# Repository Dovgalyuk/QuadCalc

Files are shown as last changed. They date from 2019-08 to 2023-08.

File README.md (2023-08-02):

# QuadCalc
Arduino-based calculator displaying bin/oct/dec/hex versions of argument and result simultaneously

Schematic: https://github.com/Dovgalyuk/QuadCalc/blob/master/pcb-avr/pcb.pdf

## Flashing

Read low fuse bits into file low:

    sudo avrdude -p m2560 -c usbtiny -U lfuse:r:low:r

Write low fuse bits from file low. It should contain single FF byte:

    sudo avrdude -p m2560 -c usbtiny -U lfuse:w:low:r

Write high fuse bits from file high. It should contain single D8 byte:

    sudo avrdude -p m2560 -c usbtiny -U hfuse:w:high:r

Write the firmware image:

    sudo avrdude -p m2560 -c usbtiny -U flash:w:calc.ino.hex:i

# Links

* MK61 hardware emulator: https://gitlab.com/vitasam/mk61s
* E-ink Pi: https://github.com/a8ksh4/paper-pi-handheld
* Handheld Linux Terminal: https://hackaday.io/project/192152-handheld-linux-terminal
* The Forth Deck: http://mynor.org/my4th

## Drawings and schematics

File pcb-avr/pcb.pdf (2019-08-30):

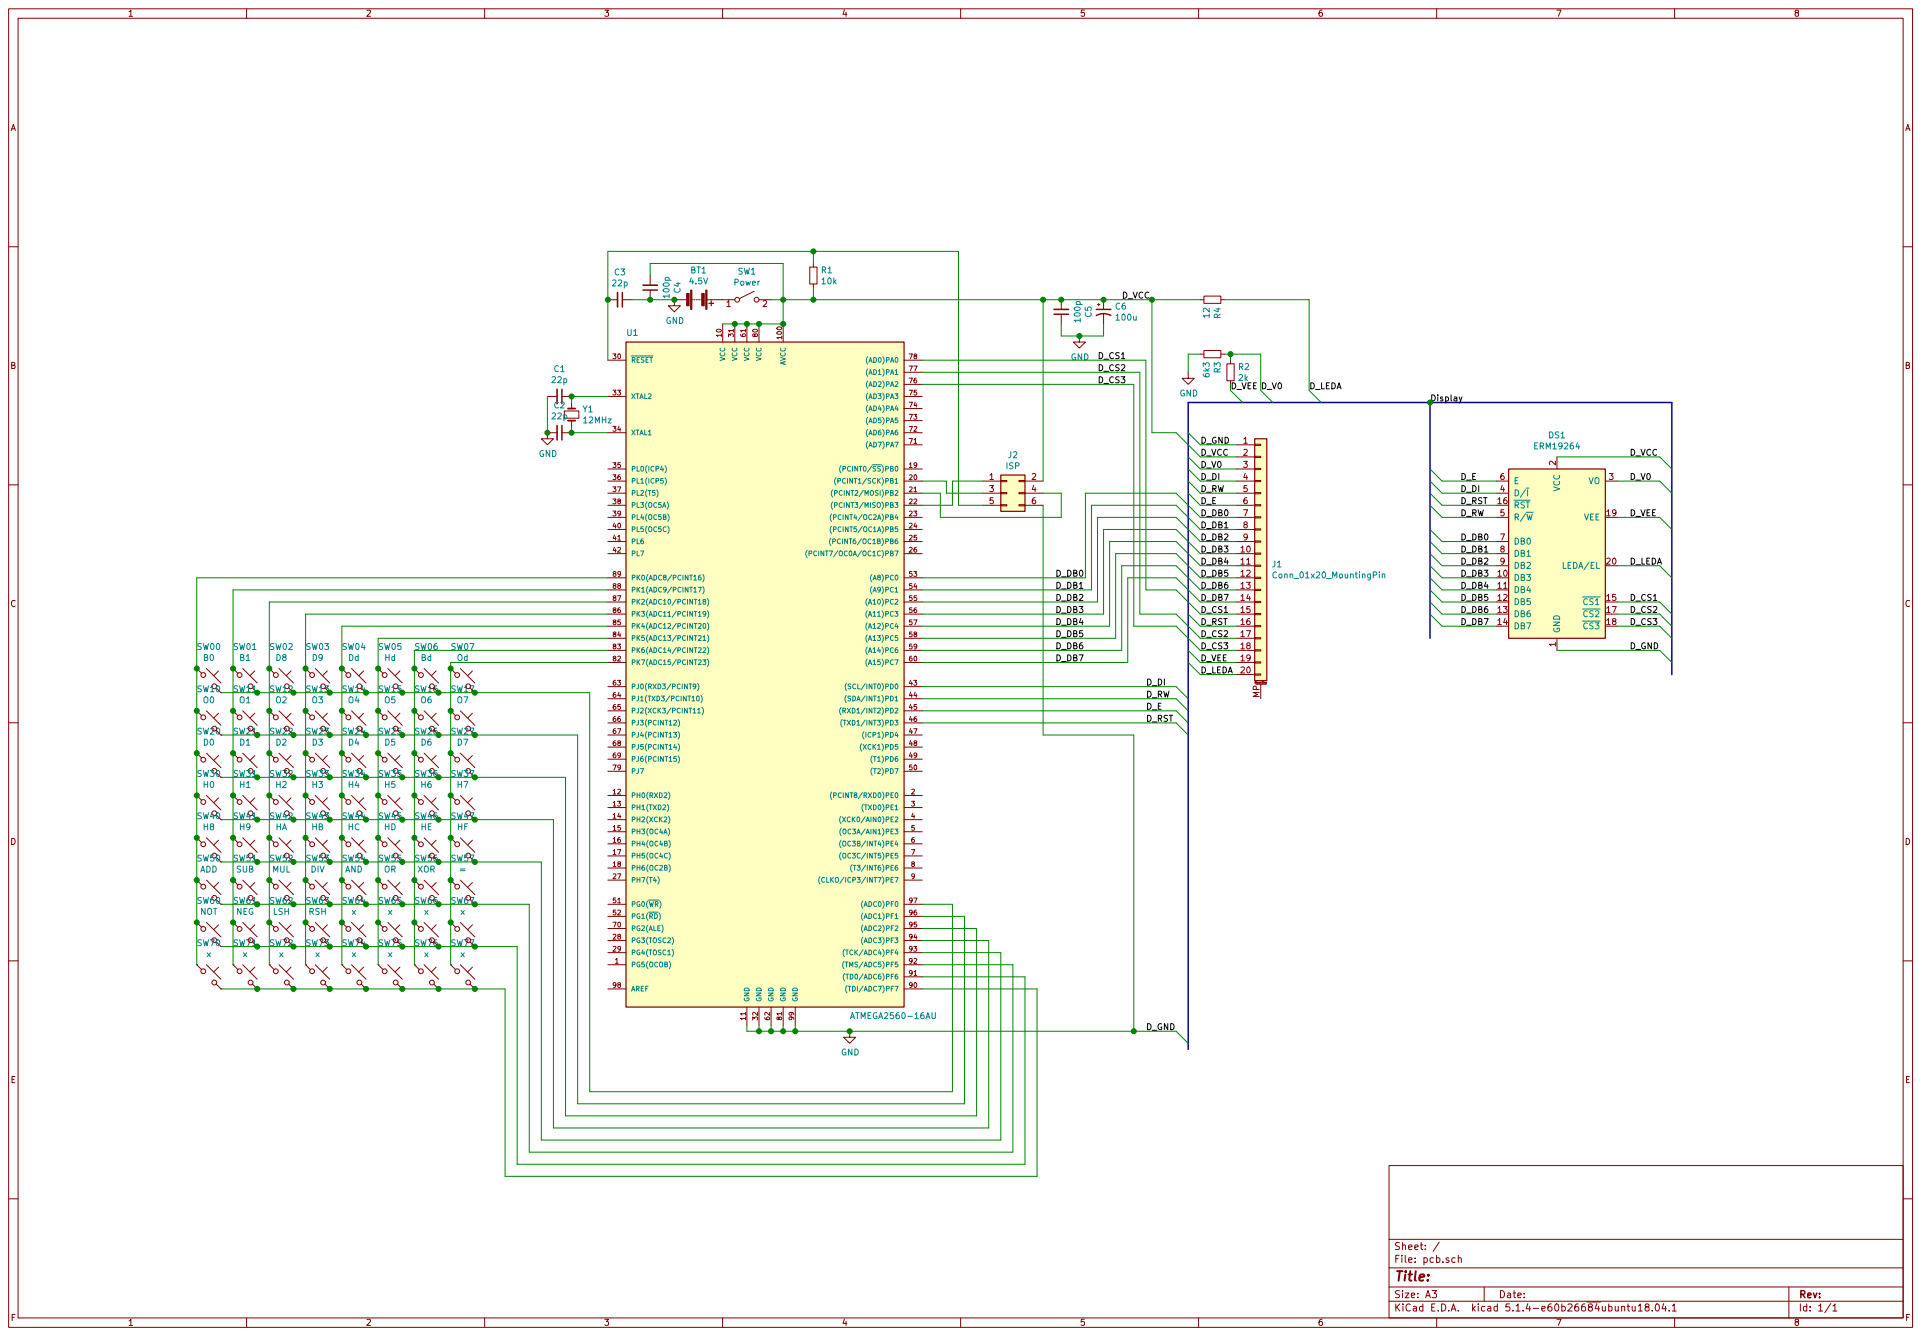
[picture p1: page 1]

File: pcb.sch Sheet: /

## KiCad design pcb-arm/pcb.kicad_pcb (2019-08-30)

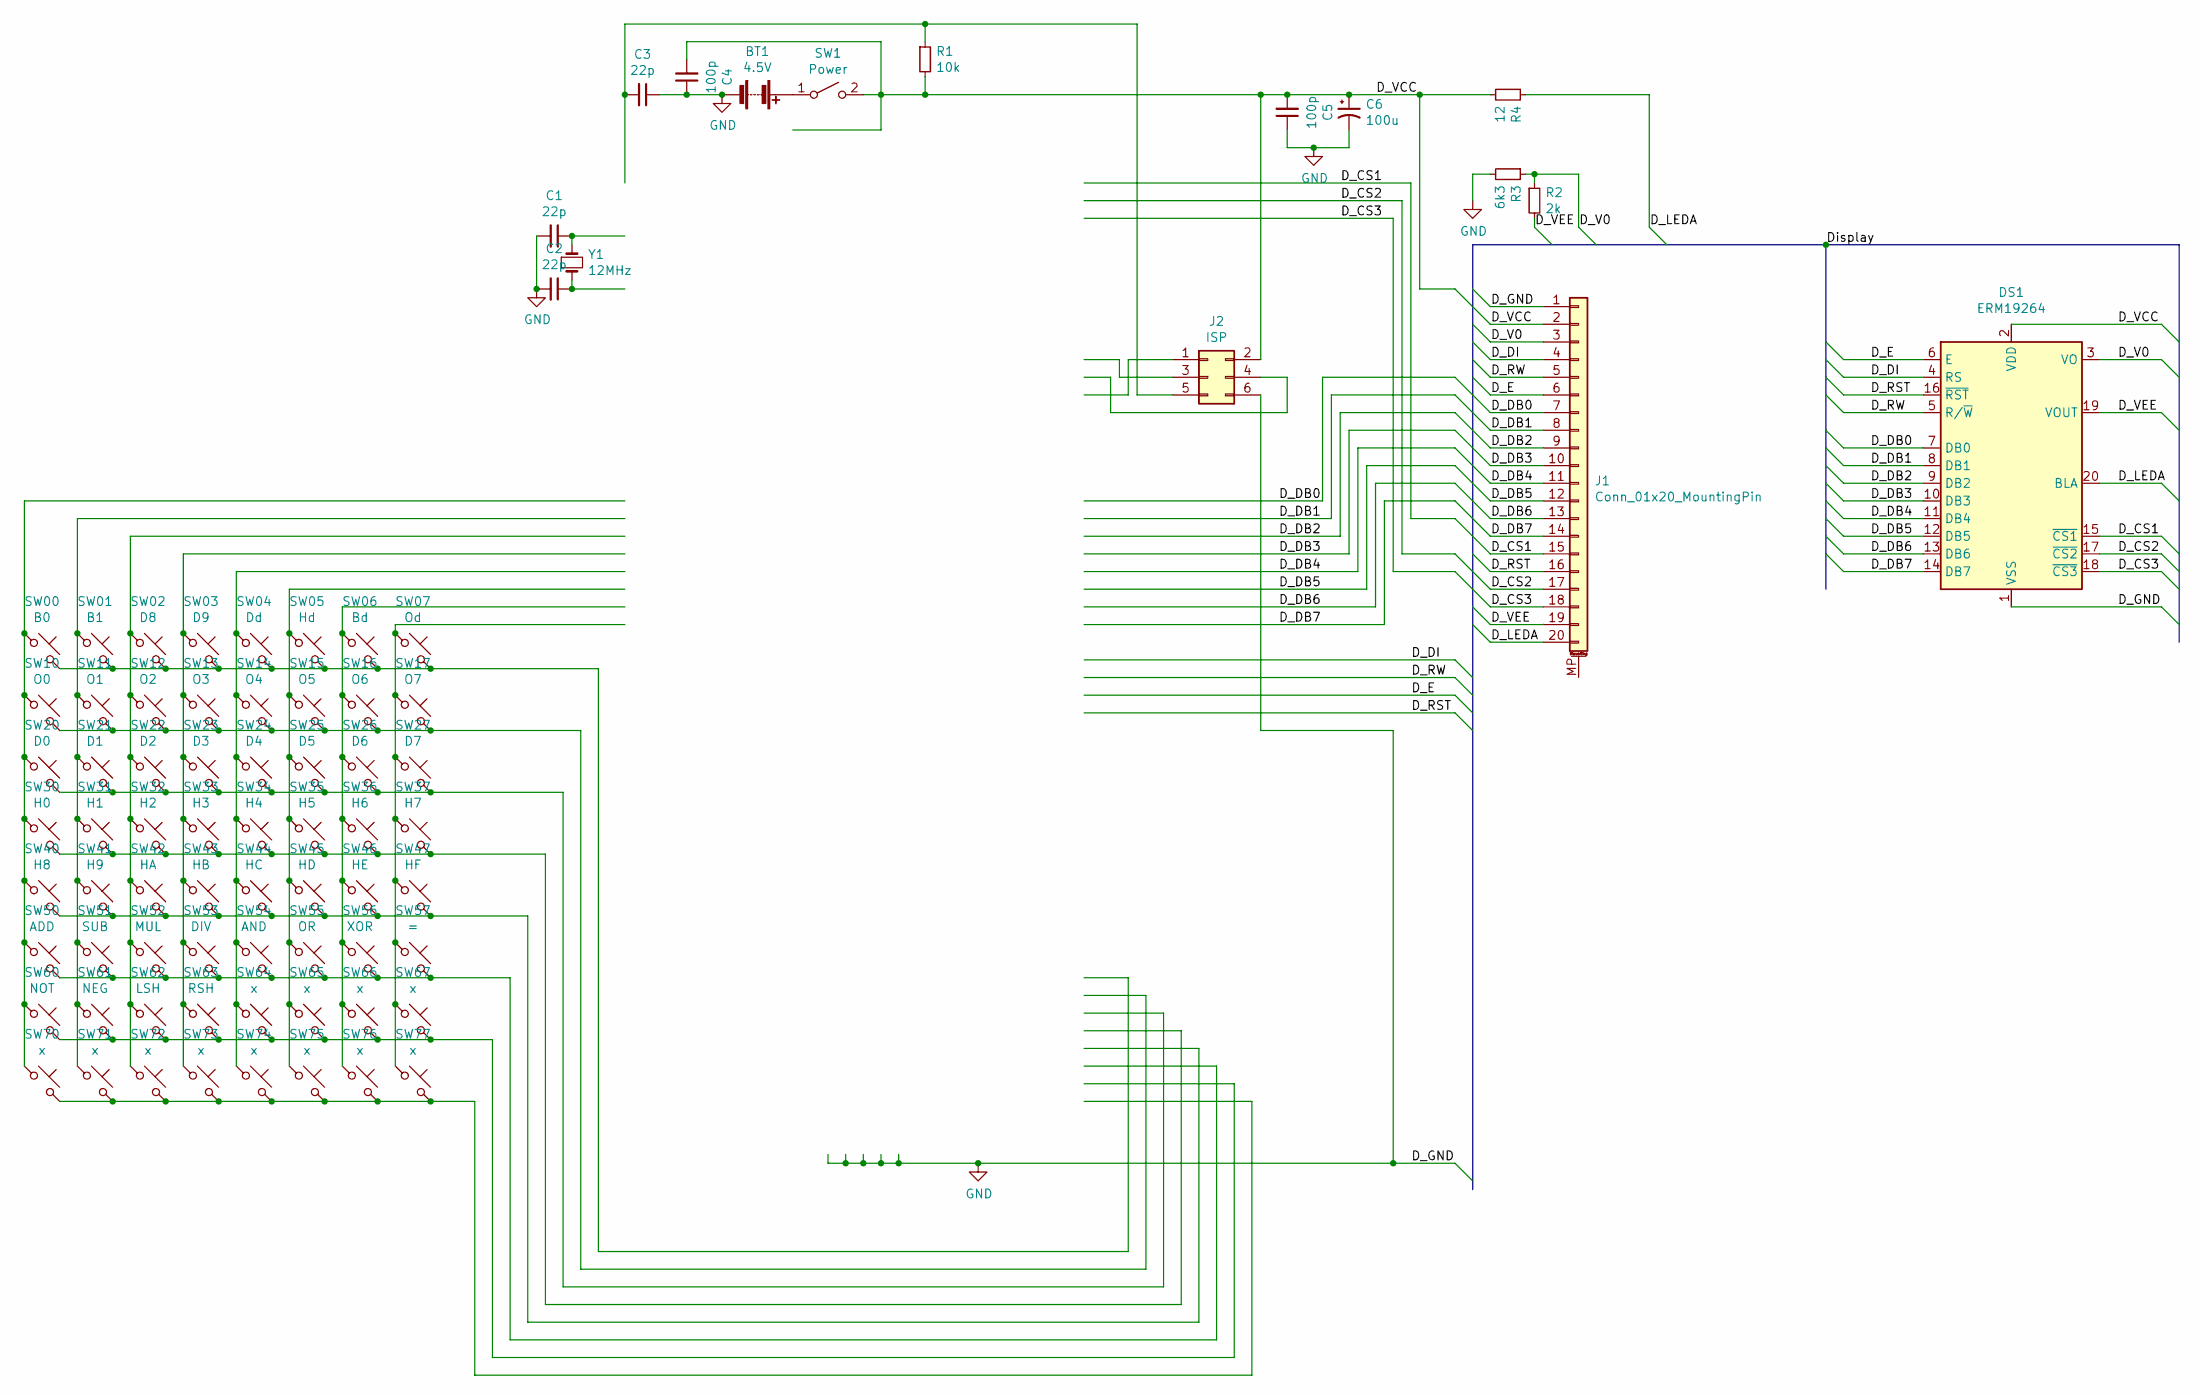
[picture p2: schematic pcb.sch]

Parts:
BT1: 4.5V; BatteryHolder_Keystone_2479_3xAAA
C1, C2, C3: 22p; C_0603_1608Metric
C4, C5: 100p; C_0603_1608Metric
C6: 100u; CP_EIA-7343-15_Kemet-W
DS1: ERM19264
J1: Conn_01x20_MountingPin; PinSocket_1x20_P2.54mm_Vertical
J2: ISP; IDC-Header_2x03_P2.54mm_Vertical
R1: 10k; R_0603_1608Metric
R2: 2k; R_0603_1608Metric
R3: 6k3; R_0603_1608Metric
R4: 12; R_0603_1608Metric
SW00: B0; SW_SPST_PTS645
SW01: B1; SW_SPST_PTS645
SW1: Power; SW_CuK_JS202011CQN_DPDT_Straight
SW02: D8; SW_SPST_PTS645
SW03: D9; SW_SPST_PTS645
SW04: Dd; SW_SPST_PTS645
SW05: Hd; SW_SPST_PTS645
SW06: Bd; SW_SPST_PTS645
SW07: Od; SW_SPST_PTS645
SW10: O0; SW_SPST_PTS645
SW11: O1; SW_SPST_PTS645
SW12: O2; SW_SPST_PTS645
SW13: O3; SW_SPST_PTS645
SW14: O4; SW_SPST_PTS645
SW15: O5; SW_SPST_PTS645
SW16: O6; SW_SPST_PTS645
SW17: O7; SW_SPST_PTS645
SW20: D0; SW_SPST_PTS645
SW21: D1; SW_SPST_PTS645
SW22: D2; SW_SPST_PTS645
SW23: D3; SW_SPST_PTS645
SW24: D4; SW_SPST_PTS645
SW25: D5; SW_SPST_PTS645
SW26: D6; SW_SPST_PTS645
SW27: D7; SW_SPST_PTS645
SW30: H0; SW_SPST_PTS645
SW31: H1; SW_SPST_PTS645
SW32: H2; SW_SPST_PTS645
SW33: H3; SW_SPST_PTS645
SW34: H4; SW_SPST_PTS645
SW35: H5; SW_SPST_PTS645
SW36: H6; SW_SPST_PTS645
SW37: H7; SW_SPST_PTS645
SW40: H8; SW_SPST_PTS645
SW41: H9; SW_SPST_PTS645
SW42: HA; SW_SPST_PTS645
SW43: HB; SW_SPST_PTS645
SW44: HC; SW_SPST_PTS645
SW45: HD; SW_SPST_PTS645
SW46: HE; SW_SPST_PTS645
SW47: HF; SW_SPST_PTS645
SW50: ADD; SW_SPST_PTS645
SW51: SUB; SW_SPST_PTS645
SW52: MUL; SW_SPST_PTS645
SW53: DIV; SW_SPST_PTS645
SW54: AND; SW_SPST_PTS645
SW55: OR; SW_SPST_PTS645
SW56: XOR; SW_SPST_PTS645
SW57: =; SW_SPST_PTS645
SW60: NOT; SW_SPST_PTS645
SW61: NEG; SW_SPST_PTS645
SW62: LSH; SW_SPST_PTS645
SW63: RSH; SW_SPST_PTS645
SW64, SW65, SW66, SW67, SW70, SW71, SW72, SW73, SW74, SW75, SW76, SW77: x; SW_SPST_PTS645
Y1: 12MHz; Crystal_SMD_SeikoEpson_MC405-2Pin_9.6x4.1mm_HandSoldering

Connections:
/D_CS1: DS1.15 (~CS1~), J1.15; also elsewhere on the board
/D_CS2: DS1.17 (~CS2~), J1.17; also elsewhere on the board
/D_CS3: DS1.18 (~CS3~), J1.18; also elsewhere on the board
/D_DB0: DS1.7 (DB0), J1.7; also elsewhere on the board
/D_DB1: DS1.8 (DB1), J1.8; also elsewhere on the board
/D_DB2: DS1.9 (DB2), J1.9; also elsewhere on the board
/D_DB3: DS1.10 (DB3), J1.10; also elsewhere on the board
/D_DB4: DS1.11 (DB4), J1.11; also elsewhere on the board
/D_DB5: DS1.12 (DB5), J1.12; also elsewhere on the board
/D_DB6: DS1.13 (DB6), J1.13; also elsewhere on the board
/D_DB7: DS1.14 (DB7), J1.14; also elsewhere on the board
/D_DI: DS1.4 (RS), J1.4; also elsewhere on the board
/D_E: DS1.6 (E), J1.6; also elsewhere on the board
/D_LEDA: DS1.20 (BLA), J1.20, R4.1
/D_RST: DS1.16 (~RST~), J1.16; also elsewhere on the board
/D_RW: DS1.5 (R/~W~), J1.5; also elsewhere on the board
/D_V0: DS1.3 (VO), J1.3, R2.1, R3.1
/D_VCC: C4.2, C5.2, C6.1, DS1.2 (VDD), J1.2, J2.2, R1.2, R4.2, SW1.2 (B); also elsewhere on the board
/D_VEE: DS1.19 (VOUT), J1.19, R2.2
GND: BT1.2 (-), C1.2, C2.2, C3.1, C4.1, C5.1, C6.2, DS1.1 (VSS), J1.1, J2.6, R3.2; also elsewhere on the board
unnamed: BT1.1 (+), SW1.1 (A)
unnamed 21: C1.1, Y1.1; also elsewhere on the board
unnamed 22: C2.1, Y1.2; also elsewhere on the board
unnamed 23: C3.2, J2.5, R1.1; also elsewhere on the board
unnamed 24: J2.1; also elsewhere on the board
unnamed 25: J2.3; also elsewhere on the board
unnamed 26: J2.4; also elsewhere on the board
unnamed 27: SW00.1, SW10.1, SW20.1, SW30.1, SW40.1, SW50.1, SW60.1, SW70.1; also elsewhere on the board
unnamed 28: SW00.2, SW01.2, SW02.2, SW03.2, SW04.2, SW05.2, SW06.2, SW07.2; also elsewhere on the board
unnamed 29: SW01.1, SW11.1, SW21.1, SW31.1, SW41.1, SW51.1, SW61.1, SW71.1; also elsewhere on the board
unnamed 30: SW02.1, SW12.1, SW22.1, SW32.1, SW42.1, SW52.1, SW62.1, SW72.1; also elsewhere on the board
unnamed 31: SW03.1, SW13.1, SW23.1, SW33.1, SW43.1, SW53.1, SW63.1, SW73.1; also elsewhere on the board
unnamed 32: SW04.1, SW14.1, SW24.1, SW34.1, SW44.1, SW54.1, SW64.1, SW74.1; also elsewhere on the board
unnamed 33: SW05.1, SW15.1, SW25.1, SW35.1, SW45.1, SW55.1, SW65.1, SW75.1; also elsewhere on the board
unnamed 34: SW06.1, SW16.1, SW26.1, SW36.1, SW46.1, SW56.1, SW66.1, SW76.1; also elsewhere on the board
unnamed 35: SW07.1, SW17.1, SW27.1, SW37.1, SW47.1, SW57.1, SW67.1, SW77.1; also elsewhere on the board
unnamed 36: SW10.2, SW11.2, SW12.2, SW13.2, SW14.2, SW15.2, SW16.2, SW17.2; also elsewhere on the board
unnamed 37: SW20.2, SW21.2, SW22.2, SW23.2, SW24.2, SW25.2, SW26.2, SW27.2; also elsewhere on the board
unnamed 38: SW30.2, SW31.2, SW32.2, SW33.2, SW34.2, SW35.2, SW36.2, SW37.2; also elsewhere on the board
unnamed 39: SW40.2, SW41.2, SW42.2, SW43.2, SW44.2, SW45.2, SW46.2, SW47.2; also elsewhere on the board
unnamed 40: SW50.2, SW51.2, SW52.2, SW53.2, SW54.2, SW55.2, SW56.2, SW57.2; also elsewhere on the board
unnamed 41: SW60.2, SW61.2, SW62.2, SW63.2, SW64.2, SW65.2, SW66.2, SW67.2; also elsewhere on the board
unnamed 42: SW70.2, SW71.2, SW72.2, SW73.2, SW74.2, SW75.2, SW76.2, SW77.2; also elsewhere on the board

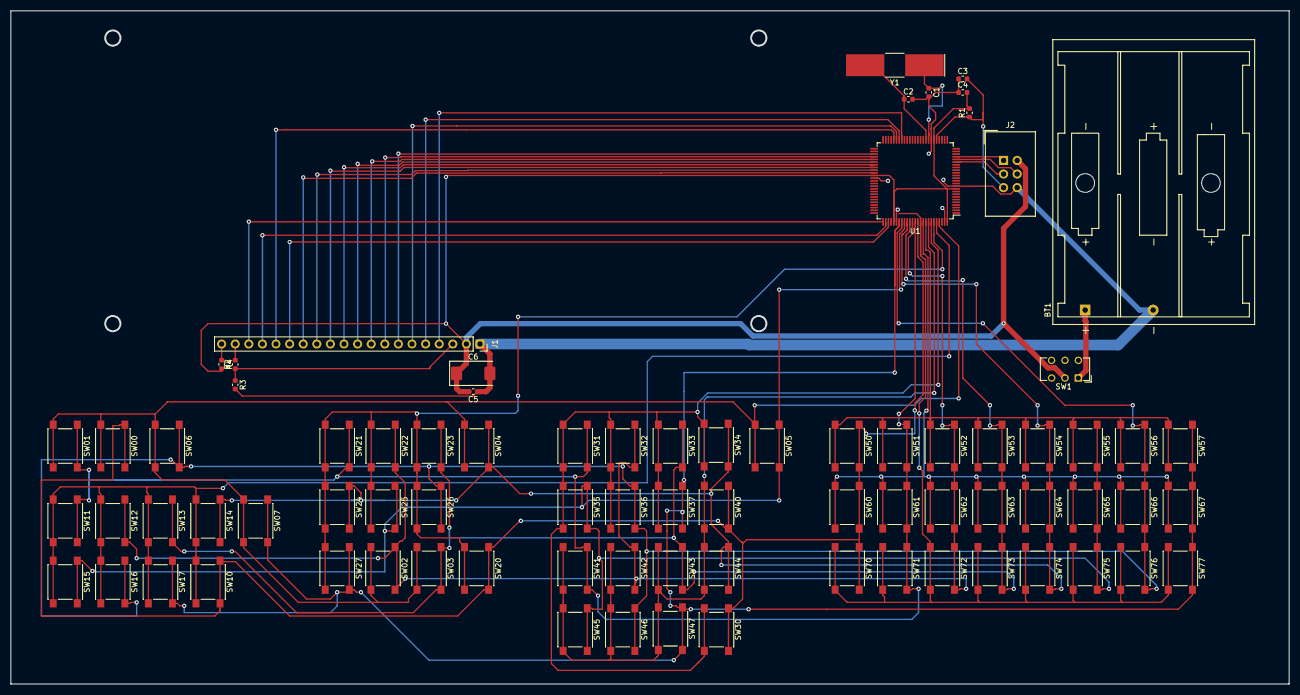
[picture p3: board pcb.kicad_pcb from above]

Board: 2 copper layers, 238.8 x 125.7 mm, 80 parts (0 on the bottom side), 43 nets.

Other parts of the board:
U1: ATMEGA2560-16AU; TQFP-100_14x14mm_P0.5mm

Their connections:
/D_CS1: U1.78; also elsewhere on the board
/D_CS2: U1.77; also elsewhere on the board
/D_CS3: U1.76; also elsewhere on the board
/D_DB0: U1.53; also elsewhere on the board
/D_DB1: U1.54; also elsewhere on the board
/D_DB2: U1.55; also elsewhere on the board
/D_DB3: U1.56; also elsewhere on the board
/D_DB4: U1.57; also elsewhere on the board
/D_DB5: U1.58; also elsewhere on the board
/D_DB6: U1.59; also elsewhere on the board
/D_DB7: U1.60; also elsewhere on the board
/D_DI: U1.43; also elsewhere on the board
/D_E: U1.45; also elsewhere on the board
/D_RST: U1.46; also elsewhere on the board
/D_RW: U1.44; also elsewhere on the board
/D_VCC: U1.10, U1.31, U1.61, U1.80, U1.100; also elsewhere on the board
GND: U1.11, U1.32, U1.62, U1.81, U1.99; also elsewhere on the board
unnamed 21: U1.33; also elsewhere on the board
unnamed 22: U1.34; also elsewhere on the board
unnamed 23: U1.30; also elsewhere on the board
unnamed 24: U1.22; also elsewhere on the board
unnamed 25: U1.20; also elsewhere on the board
unnamed 26: U1.21; also elsewhere on the board
unnamed 27: U1.89; also elsewhere on the board
unnamed 28: U1.97; also elsewhere on the board
unnamed 29: U1.88; also elsewhere on the board
unnamed 30: U1.87; also elsewhere on the board
unnamed 31: U1.86; also elsewhere on the board
unnamed 32: U1.85; also elsewhere on the board
unnamed 33: U1.84; also elsewhere on the board
unnamed 34: U1.83; also elsewhere on the board
unnamed 35: U1.82; also elsewhere on the board
unnamed 36: U1.96; also elsewhere on the board
unnamed 37: U1.95; also elsewhere on the board
unnamed 38: U1.94; also elsewhere on the board
unnamed 39: U1.93; also elsewhere on the board
unnamed 40: U1.92; also elsewhere on the board
unnamed 41: U1.91; also elsewhere on the board
unnamed 42: U1.90; also elsewhere on the board

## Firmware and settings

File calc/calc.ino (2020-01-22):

#define PIN_RS 21
#define PIN_RW 20
#define PIN_E  19
#define PIN_RST 18
#define PIN_DB0 37
#define PIN_DB1 36
#define PIN_DB2 35
#define PIN_DB3 34
#define PIN_DB4 33
#define PIN_DB5 32
#define PIN_DB6 31
#define PIN_DB7 30
#define PIN_CS1 22
#define PIN_CS2 23
#define PIN_CS3 24

#define PIN_KEYBOARD_COL A8
#define PIN_KEYBOARD_ROW A0

enum Keys
{
  K_B0, K_B1,
  K_O0, K_O1, K_O2, K_O3, K_O4, K_O5, K_O6, K_O7,
  K_D0, K_D1, K_D2, K_D3, K_D4, K_D5, K_D6, K_D7, K_D8, K_D9,
  K_H0, K_H1, K_H2, K_H3, K_H4, K_H5, K_H6, K_H7, K_H8, K_H9, K_HA, K_HB, K_HC, K_HD, K_HE, K_HF,
  K_Bd, K_Od, K_Dd, K_Hd, // delete
  K_ADD, K_SUB, K_MUL, K_DIV, K_AND, K_OR, K_XOR, K_OK,
  K_NOT, K_NEG, K_LSH, K_RSH,
};

static const uint8_t keymap[] PROGMEM = {
  K_B0, K_B1, K_D8, K_D9, K_Dd, K_Hd, K_Bd, K_Od,
  K_O0, K_O1, K_O2, K_O3, K_O4, K_O5, K_O6, K_O7,
  K_D0, K_D1, K_D2, K_D3, K_D4, K_D5, K_D6, K_D7,
  K_H0, K_H1, K_H2, K_H3, K_H4, K_H5, K_H6, K_H7,
  K_H8, K_H9, K_HA, K_HB, K_HC, K_HD, K_HE, K_HF,
  K_ADD, K_SUB, K_MUL, K_DIV, K_AND, K_OR, K_XOR, K_OK,
  K_NOT, K_NEG, K_LSH, K_RSH,
};


void sendCommand(uint8_t part, uint8_t b)
{
//  DDRC = 0xff;
//  PORTD &= ~5;
//  PORTC = b;
//  PORTD |= 4;
//  DDRC = 0x00;

  for (int i = 0 ; i < 8 ; ++i)
    pinMode(PIN_DB0 - i, OUTPUT);

  digitalWrite(PIN_CS1 + part, LOW);

  digitalWrite(PIN_RS, LOW);
  digitalWrite(PIN_RW, LOW);
  for (int i = 0 ; i < 8 ; ++i)
    digitalWrite(PIN_DB0 - i, ((b >> i) & 1));
  digitalWrite(PIN_E, LOW);
  delayMicroseconds(1);
  digitalWrite(PIN_E, HIGH);
  delayMicroseconds(1);
  digitalWrite(PIN_E, LOW);
  delayMicroseconds(1);

  digitalWrite(PIN_CS1 + part, HIGH);
}

void sendData(uint8_t part, uint8_t b)
{
//  PORTD |= 1;
//  DDRC = 0xff;
//  PORTD &= ~4;
//  PORTC = b;
//  PORTD |= 4;
//  DDRC = 0x00;

  digitalWrite(PIN_CS1 + part, LOW);

  for (int i = 0 ; i < 8 ; ++i)
    pinMode(PIN_DB0 - i, OUTPUT);

  digitalWrite(PIN_RS, HIGH);
  digitalWrite(PIN_RW, LOW);
  for (int i = 0 ; i < 8 ; ++i)
    digitalWrite(PIN_DB0 - i, ((b >> i) & 1));
  digitalWrite(PIN_E, LOW);
  delayMicroseconds(1);
  digitalWrite(PIN_E, HIGH);
  delayMicroseconds(1);
  digitalWrite(PIN_E, LOW);
  delayMicroseconds(1);

  digitalWrite(PIN_CS1 + part, HIGH);
}

uint8_t readStatus()
{
//  DDRC = 0;
//  PORTD |= 2;
//  PORTD &= ~4;
//  uint8_t res = PORTC;
//  PORTD | 4;
//  return res;
  uint8_t res = 0;
  digitalWrite(PIN_RS, LOW);
  digitalWrite(PIN_RW, HIGH);

  for (int i = 0 ; i < 8 ; ++i)
    pinMode(PIN_DB0 - i, INPUT);
  
  digitalWrite(PIN_E, LOW);
  delayMicroseconds(1);
  digitalWrite(PIN_E, HIGH);
  delayMicroseconds(1);
  for (int i = 0 ; i < 7 ; ++i)
    res |= digitalRead(PIN_DB0 - i) << i;
  digitalWrite(PIN_E, LOW);
  delayMicroseconds(4500);
}

void setup() {
//  // put your setup code here, to run once:
//  // PORTC - data bus line
//  DDRC = 0x0;
//  // PORTD
//  //  0 RS
//  //  1 R/W
//  //  2 E
//  //  3 RST
//  DDRD = 0x0f;
//  PORTD = 0x0c;
//  // PORTA
//  //  0-2 CS1-3
//  DDRA = 0x07;
//  PORTA = 0;
//
  //Serial.begin(9600);
  //while (!Serial) {}
//
  //Serial.println("Test\n");
//
//  sendCommand(0x1f);
//
//  uint8_t d = readData();
//  Serial.println(d, HEX);
//  
//  //for (int i = 0 ; i < 64 ; ++i)
//  //  sendData(0xff);
//
//  d = readData();
//  Serial.println(d, HEX);

  pinMode(PIN_RS, OUTPUT);
  pinMode(PIN_RW, OUTPUT);
  pinMode(PIN_E, OUTPUT);
  pinMode(PIN_RST, OUTPUT);

  for (int i = 0 ; i < 8 ; ++i)
    pinMode(PIN_DB0 - i, OUTPUT);
  pinMode(PIN_CS1, OUTPUT);
  pinMode(PIN_CS2, OUTPUT);
  pinMode(PIN_CS3, OUTPUT);

  for (int i = 0 ; i < 8 ; ++i)
  {
    pinMode(PIN_KEYBOARD_ROW + i, OUTPUT);
    digitalWrite(PIN_KEYBOARD_ROW + i, HIGH);
    pinMode(PIN_KEYBOARD_COL + i, INPUT_PULLUP);
  }

  digitalWrite(PIN_CS1, HIGH);
  digitalWrite(PIN_CS2, HIGH);
  digitalWrite(PIN_CS3, HIGH);

  digitalWrite(PIN_RST, LOW);

  delay(100);

  digitalWrite(PIN_RST, HIGH);

  delay(100);

  //Serial.println(readStatus());

  // on command
  sendCommand(0, 0x3f);
  sendCommand(1, 0x3f);
  sendCommand(2, 0x3f);

  //Serial.println(readStatus());

  //Serial.println(readStatus());

  // off command
  //sendCommand(1, 0x3e);
  
  //Serial.println(readStatus());

//  digitalWrite(PIN_RST, LOW);
//  delayMicroseconds(5);
//  Serial.println(readStatus());

  //sendCommand(0x40);
  //sendCommand(0xb8);
  //sendCommand(0xc0);

  // clear screen
  for (int part = 0 ; part < 3 ; ++part)
    for (int p = 0 ; p < 8 ; ++p)
    {
      sendCommand(part, 0xb8 + p);
      for (int i = 0 ; i < 64 ; ++i)
        sendData(part, 0x00);
    }

}

// 2: 192 / 32 = 6
// 8: 192 / 11 = 17
// 10: 192 / 11 = 17
// 16: 192 / 8 = 24

// upper bits down
#define PART_W 64

#define FONT_W 5
const uint8_t font[] PROGMEM = {
  B01111100,
  B10000010,
  B10000010,
  B01111100,
  B00000000,

  B00000000,
  B00000100,
  B11111110,
  B00000000,
  B00000000,

  B11000100,
  B10100010,
  B10010010,
  B10001100,
  B00000000,

  B01000010,
  B10010010,
  B10011010,
  B01100110,
  B00000000,

  B00011110,
  B00010000,
  B00010000,
  B11111110,
  B00000000,

  B01001110,
  B10001010,
  B10001010,
  B01110010,
  B00000000,

  B01111100,
  B10010010,
  B10010010,
  B01100000,
  B00000000,

  B00000010,
  B00000010,
  B11111010,
  B00000110,
  B00000000,

  B01101100,
  B10010010,
  B10010010,
  B01101100,
  B00000000,

  B00001100,
  B10010010,
  B10010010,
  B01111100,
  B00000000,

  B11111100,
  B00010010,
  B00010010,
  B11111100,
  B00000000,

  B11111110,
  B10010010,
  B10010010,
  B01101100,
  B00000000,

  B01111100,
  B10000010,
  B10000010,
  B01000100,
  B00000000,

  B11111110,
  B10000010,
  B10000010,
  B01111100,
  B00000000,

  B11111110,
  B10010010,
  B10010010,
  B10000010,
  B00000000,

  B11111110, // 0f
  B00010010,
  B00010010,
  B00000010,
  B00000000,

  B00000000, // 10
  B00000000,
  B00000000,
  B00000000,
  B00000000,

  B00010000, // 11
  B00010000,
  B11111110,
  B00010000,
  B00010000,

  B00010000, // 12
  B00010000,
  B00010000,
  B00010000,
  B00010000,

  B01000100, // 13
  B00101000,
  B00010000,
  B00101000,
  B01000100,

  B01000000, // 14
  B00100000,
  B00010000,
  B00001000,
  B00000100,

  B01101100, // 15
  B10010010,
  B10110010,
  B01001100,
  B10100000,

  B00000000, // 16
  B00000000,
  B11111110,
  B00000000,
  B00000000,

  B00001000, // 17
  B00000100,
  B00000010,
  B00000100,
  B00001000,
};

static int lineX;
static uint8_t lineSeg;

static void lineSend(uint8_t b)
{
  sendData(lineSeg, b);
  ++lineX;
  if (lineX == PART_W)
  {
    lineX = 0;
    lineSeg = (lineSeg + 1) % 3;
  }
}

static void drawChar(uint8_t c)
{
    for (int j = 0 ; j < FONT_W ; ++j)
    {
      uint8_t b = pgm_read_byte(font + c * FONT_W + j);
      lineSend(b);
    }
}

static void setupPage(uint8_t page)
{
  uint8_t part;
  for (part = 0 ; part < 3 ; ++part)
  {
    sendCommand(part, 0xb8 + page);
    // y = 0
    sendCommand(part, 0x40 + 0);
  }
  lineSeg = 0;
  lineX = 0;
}

static void drawSpace(uint32_t v)
{
  while (v--)
  {
    lineSend(0);
  }
}

static void drawBin(uint32_t v)
{
  uint32_t mask = 0x80000000;
  for (int i = 0 ; i < 32 ; ++i, mask >>= 1)
  {
    uint8_t c = 0;
    if (v & mask)
      c = 1;
    drawChar(c);
    //lineSend(c);
    if ((i & 3) == 3)
    {
      drawSpace(3);
    }
  }
}

static void drawOct(uint32_t v)
{
  int shift = 30;
  for (int i = 0 ; i < 11 ; ++i, shift -= 3)
  {
    uint8_t c = (v >> shift) & 7;
    drawChar(c);
  }
}

static void drawDec(uint32_t v)
{
  int8_t d[10];
  for (int8_t i = 0 ; i < 10 ; ++i)
  {
    d[i] = v % 10;
    v = v / 10;
  }
  for (int8_t i = 9 ; i >= 0 ; --i)
    drawChar(d[i]);
}

static void drawHex(uint32_t v)
{
  int shift = 28;
  for (int i = 0 ; i < 8 ; ++i, shift -= 4)
  {
    uint8_t c = (v >> shift) & 0xf;
    drawChar(c);
  }
}

static uint32_t completeOp(int8_t op, uint32_t acc, uint32_t v)
{
  switch (op)
  {
  case K_ADD:
    return acc + v;
  case K_SUB:
    return acc - v;
  case K_MUL:
    return acc * v;
  case K_DIV:
    return v ? acc / v : 0;
  case K_AND:
    return acc & v;
  case K_OR:
    return acc | v;
  case K_XOR:
    return acc ^ v;
  default:
    return v;
  }  
}

static uint8_t getOpChar(int8_t op)
{
  switch (op)
  {
  case K_ADD:
    return 0x11;
  case K_SUB:
    return 0x12;
  case K_MUL:
    return 0x13;
  case K_DIV:
    return 0x14;
  case K_AND:
    return 0x15;
  case K_OR:
    return 0x16;
  case K_XOR:
    return 0x17;
  default:
    return 0x10;
  }
}

void loop()
{
  uint32_t v = 0;
  uint32_t acc = 0;
  int8_t op = -1;
  while (true)
  {
    setupPage(0);
    drawSpace(FONT_W + 3);
    drawBin(acc);

    setupPage(1);
    drawSpace(FONT_W * 22 + 3 * 8);
    drawOct(acc);
    
    setupPage(2);
    drawSpace(FONT_W * 23 + 3 * 8);
    drawDec(acc);
    
    setupPage(3);
    drawSpace(FONT_W * 25 + 3 * 8);
    drawHex(acc);
    
    setupPage(4);
    drawChar(getOpChar(op));
    drawSpace(3);
    drawBin(v);
    
    setupPage(5);
    drawSpace(FONT_W * 22 + 3 * 8);
    drawOct(v);
    
    setupPage(6);
    drawSpace(FONT_W * 23 + 3 * 8);
    drawDec(v);
    
    setupPage(7);
    drawSpace(FONT_W * 25 + 3 * 8);
    drawHex(v);

    uint32_t lastKey = millis();
    while (lastKey + 200 > millis())
      ;
    while (true)
    {
      int8_t key = -1;
      for (int i = 0 ; i < 8 ; ++i)
      {
        digitalWrite(PIN_KEYBOARD_ROW + i, LOW);
        for (int j = 0 ; j < 8 ; ++j)
          if (!digitalRead(PIN_KEYBOARD_COL + j))
            key = i * 8 + j;
        digitalWrite(PIN_KEYBOARD_ROW + i, HIGH);
      }
      if (key >= 0)
      {
        key = pgm_read_byte(keymap + key);
        switch (key)
        {
        case K_B0...K_B1:
          v = v * 2 + key - K_B0;
          break;
        case K_O0...K_O7:
          v = v * 8 + key - K_O0;
          break;
        case K_D0...K_D9:
          v *= 10;
          v -= v % 10;
          v += key - K_D0;
          break;
        case K_H0...K_HF:
          v = v * 16 + key - K_H0;
          break;
        case K_Bd:
          v = v / 2;
          break;
        case K_Od:
          v = v / 8;
          break;
        case K_Dd:
          v = v / 10;
          break;
        case K_Hd:
          v = v / 16;
          break;
        case K_ADD:
        case K_SUB:
        case K_MUL:
        case K_DIV:
        case K_AND:
        case K_OR:
        case K_XOR:
          acc = completeOp(op, acc, v);
          v = 0;
          op = key;
          break;
        case K_OK:
          v = acc = completeOp(op, acc, v);
          op = -1;
          break;
        case K_NOT:
          v = ~v;
          break;
        case K_NEG:
          v = -v;
          break;
        case K_LSH:
          v <<= 1;
          break;
        case K_RSH:
          v >>= 1;
          break;
        }
        break;
      }
    }
  }
}

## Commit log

2019-08-30 Added PCB for AVR version
    [pcb-B_Cu.gbr, pcb-B_Mask.gbr, pcb-B_Paste.gbr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]
2019-08-30 Added exported schematic
2019-08-30 Added kicad patches with display module
2020-09-30 Removed upstreamed kicad stuff
2022-03-04 Readme update
    [pcb.kicad_pcb, pcb.sch]
